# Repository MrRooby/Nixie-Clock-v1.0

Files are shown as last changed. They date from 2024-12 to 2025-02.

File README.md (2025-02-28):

# Nixie Clock v1.0

An ESP32-based Nixie Clock project featuring:
- Time and date display
- Temperature and humidity readings
- Gas level alarm detection
- Bluetooth control for alarm clock

## Table of Contents
1. [Introduction](#introduction)
2. [Features](#features)
3. [Hardware Setup](#hardware-setup)
4. [Bluetooth Application](#bluetooth-application)
5. [Schematic and Board Photos](#schematic-and-board-photos)
6. [Device Photos](#device-photos)
7. [**Issues**](#issues)

## Introduction
This project displays the current time, date, temperature, and humidity on Z573M Nixie tubes. It also includes a gas sensor alarm, and Bluetooth set alarm clock connectivity.

## Features
- Displays time in HH:MM format on Nixie tubes
- Shows date in DD-MM format
- Reads temperature and humidity via a DHT22 sensor
- Detects gas levels using an MQ-9 sensor
- Allows alarm configuration via Bluetooth
- Alerts with a buzzer and LEDs

## Hardware Setup
1. Nixie tubes are connected to 170V and are driven via K155ID.
2. Drivers responsible for the lamps are connected to ESP32 via Level Shifters (3.3V to 5V)
3. Two of the drivers are connected to PCF8575 I2C port expander.
4. RTC clock is connected to the board for time keeping
5. DHT and MQ-9 sensors are connected directly to the ESP32 pins.
6. Buzzer and LEDs are connected directly to the ESP32

## Bluetooth Application
*(pending)*

## Schematic and Board Photos
Schematic

Board

## Device Photos
nixie_clock v1

## Issues
The device's current version suffers from a couple of mistakes or errors.
1. Mirrored Z573M library. **Temporary fix:** Lamps connected from the bottom of the board.
2. Board enters boot-loop. **Temporary fix:** Button connected between IO12 and GND. If pressed, the board exits the boot loop and functions properly.
3. Wrong MQ9 input voltage. Sensor requires 5V and connected trace supplies 3.3V. **Temporary fix:** Cable connected to 5V omitting on-board trace.
4. LED pins don't supply enough current via PCF8575 **Temporary fix:** LEDs connected directly to ESP32

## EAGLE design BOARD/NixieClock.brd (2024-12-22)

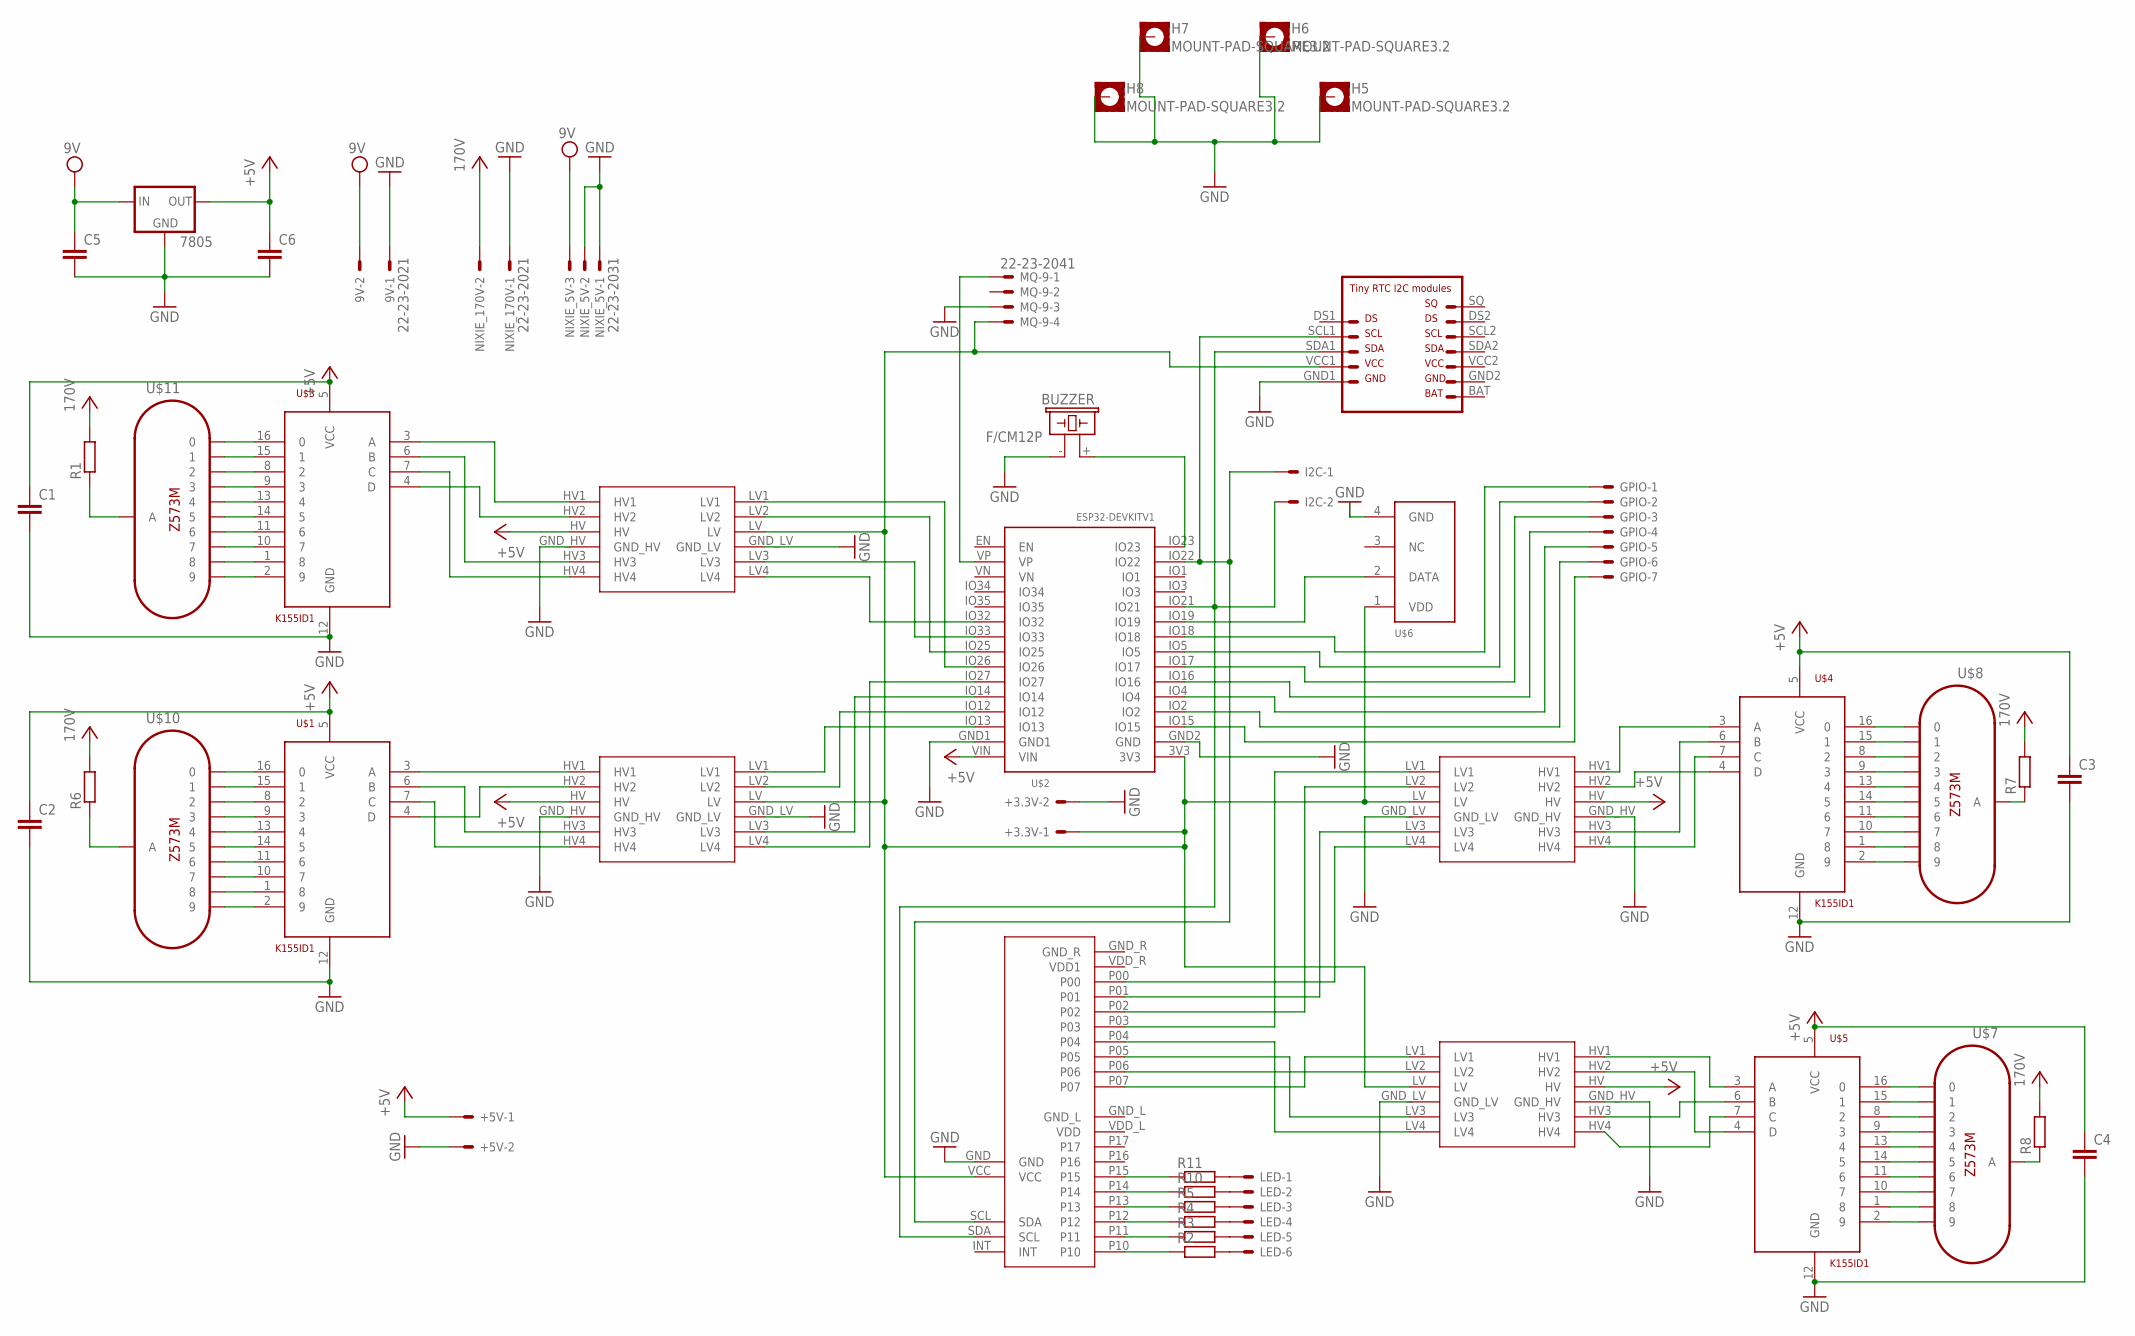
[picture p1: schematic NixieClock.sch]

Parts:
9V: 22-23-2021
7805: 78XXS
+3.3V, +5V: KK-156-2
BUZZER: F/CM12P
C1, C2, C3, C4, C5, C6: C2,5-3; C2.5-3
GPIO: KK-156-7
H5, H6, H7, H8: MOUNT-PAD-SQUARE3.2; 3,2-PAD-SQUARE
I2C: KK-156-2
LED: KK-156-6
MQ-9: 22-23-2041; MPN wyświetlacz I2C
NIXIE_5V: 22-23-2031
NIXIE_170V: 22-23-2021
R1, R2, R3, R4, R5, R6, R7, R8, R10, R11: R-EU_0204/7; 0204/7
STEP_UP_$: LEVEL-CONVERTER
U$1, U$3, U$4, U$5: K155ID1; DIP16-2.54-19.2X7.62MM
U$2: ESP32DEVKITV1; ESP32-DEVKITV1
U$6: DHT11
U$7, U$8, U$10, U$11: Z573M
U$9: RTC
U$12, U$13, U$15: LEVEL-CONVERTER
U$16: PCF8575

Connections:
3.3V: +3.3V.1, MQ-9.4, STEP_UP_$.LV, U$2.3V3, U$6.1 (VDD), U$9.VCC1, U$12.LV, U$13.LV, U$15.LV, U$16.VCC
170V: 9V.2, 7805.IN, C5.1, NIXIE_5V.3, NIXIE_170V.2, R1.2, R6.2, R7.2, R8.2
+5V: 7805.OUT, +5V.1, C1.1, C2.1, C3.1, C4.1, C6.1, STEP_UP_$.HV, U$1.5 (VCC), U$2.VIN, U$3.5 (VCC), U$4.5 (VCC), U$5.5 (VCC), U$12.HV, U$13.HV, U$15.HV
GND: 9V.1, 7805.GND, +3.3V.2, +5V.2, BUZZER.- (2), C1.2, C2.2, C3.2, C4.2, C5.2, C6.2, H5.B3,2, H6.B3,2, H7.B3,2, H8.B3,2, MQ-9.3, NIXIE_5V.1, NIXIE_5V.2, NIXIE_170V.1, STEP_UP_$.GND_HV, STEP_UP_$.GND_LV, U$1.12 (GND), U$2.GND1, U$2.GND2 (GND), U$3.12 (GND), U$4.12 (GND), U$5.12 (GND), U$6.4 (GND), U$9.GND1, U$12.GND_HV, U$12.GND_LV, U$13.GND_HV, U$13.GND_LV, U$15.GND_HV, U$15.GND_LV, U$16.GND
unnamed: STEP_UP_$.HV1, U$5.3 (A)
unnamed: STEP_UP_$.HV2, U$5.4 (D)
unnamed: STEP_UP_$.HV3, U$5.6 (B)
unnamed: STEP_UP_$.HV4, U$5.7 (C)
unnamed: U$15.LV4, U$16.P00
unnamed: U$4.3 (A), U$15.HV1
unnamed: U$4.4 (D), U$15.HV2
unnamed: U$4.6 (B), U$15.HV3
unnamed: U$3.3 (A), U$13.HV1
unnamed: U$3.4 (D), U$13.HV2
unnamed: U$3.6 (B), U$13.HV3
unnamed: U$3.7 (C), U$13.HV4
unnamed: U$1.3 (A), U$12.HV1
unnamed: U$1.4 (D), U$12.HV2
unnamed: U$1.6 (B), U$12.HV3
unnamed: U$1.7 (C), U$12.HV4
unnamed: U$3.16 (0), U$11.K0 (0)
unnamed: U$3.15 (1), U$11.K1 (1)
unnamed: U$3.8 (2), U$11.K2 (2)
unnamed: U$3.9 (3), U$11.K3 (3)
unnamed: U$3.13 (4), U$11.K4 (4)
unnamed: U$3.14 (5), U$11.K5 (5)
unnamed: U$3.11 (6), U$11.K6 (6)
unnamed: U$3.10 (7), U$11.K7 (7)
unnamed: U$3.1 (8), U$11.K8 (8)
unnamed: U$3.2 (9), U$11.K9 (9)
unnamed: U$1.16 (0), U$10.K0 (0)
unnamed: U$1.15 (1), U$10.K1 (1)
unnamed: U$1.8 (2), U$10.K2 (2)
unnamed: U$1.9 (3), U$10.K3 (3)
unnamed: U$1.13 (4), U$10.K4 (4)
unnamed: U$1.14 (5), U$10.K5 (5)
unnamed: U$1.11 (6), U$10.K6 (6)
unnamed: U$1.10 (7), U$10.K7 (7)
unnamed: U$1.1 (8), U$10.K8 (8)
unnamed: U$1.2 (9), U$10.K9 (9)
unnamed: U$5.16 (0), U$7.K0 (0)
unnamed: U$5.15 (1), U$7.K1 (1)
unnamed: U$5.8 (2), U$7.K2 (2)
unnamed: U$5.9 (3), U$7.K3 (3)
unnamed: U$5.13 (4), U$7.K4 (4)
unnamed: U$5.14 (5), U$7.K5 (5)
unnamed: U$5.11 (6), U$7.K6 (6)
unnamed: U$5.10 (7), U$7.K7 (7)
unnamed: U$5.1 (8), U$7.K8 (8)
unnamed: U$5.2 (9), U$7.K9 (9)
unnamed: U$4.2 (9), U$8.K9 (9)
unnamed: U$4.1 (8), U$8.K8 (8)
unnamed: U$4.10 (7), U$8.K7 (7)
unnamed: U$4.11 (6), U$8.K6 (6)
unnamed: U$4.14 (5), U$8.K5 (5)
unnamed: U$4.13 (4), U$8.K4 (4)
unnamed: U$4.9 (3), U$8.K3 (3)
unnamed: U$4.8 (2), U$8.K2 (2)
unnamed: U$4.15 (1), U$8.K1 (1)
unnamed: U$4.16 (0), U$8.K0 (0)
unnamed: U$15.LV3, U$16.P01
unnamed: U$2.IO27, U$12.LV4
unnamed: I2C.1, U$2.IO22, U$9.SCL1, U$16.SCL (SDA)
unnamed: I2C.2, U$2.IO21, U$9.SDA1, U$16.SDA (SCL)
unnamed: BUZZER.+ (1), U$2.IO23
unnamed: U$15.LV2, U$16.P02
unnamed: MQ-9.1, U$2.VP
unnamed: U$15.LV1, U$16.P03
unnamed: STEP_UP_$.LV4, U$16.P04
unnamed: STEP_UP_$.LV3, U$16.P05
unnamed: STEP_UP_$.LV2, U$16.P06
unnamed: STEP_UP_$.LV1, U$16.P07
unnamed: U$2.IO19, U$6.2 (DATA)
unnamed: GPIO.1, U$2.IO18
unnamed: GPIO.2, U$2.IO5
unnamed: U$2.IO26, U$13.LV1
unnamed: U$2.IO25, U$13.LV2
unnamed: U$2.IO33, U$13.LV3
unnamed: U$2.IO32, U$13.LV4
unnamed: U$2.IO13, U$12.LV1
unnamed: U$2.IO12, U$12.LV2
unnamed: U$2.IO14, U$12.LV3
unnamed: R8.1, U$7.A
unnamed: R7.1, U$8.A
unnamed: R6.1, U$10.A
unnamed: R1.1, U$11.A
unnamed: GPIO.3, U$2.IO17
unnamed: R2.1, U$16.P10
unnamed: R3.1, U$16.P11
unnamed: R4.1, U$16.P12
unnamed: R5.1, U$16.P13
unnamed: R10.1, U$16.P14
unnamed: R11.1, U$16.P15
unnamed: LED.1, R11.2
unnamed: LED.2, R10.2
unnamed: LED.3, R5.2
unnamed: LED.4, R4.2
unnamed: LED.5, R3.2
unnamed: LED.6, R2.2
unnamed: GPIO.4, U$2.IO16
unnamed: GPIO.5, U$2.IO4
unnamed: GPIO.6, U$2.IO2
unnamed: GPIO.7, U$2.IO15
unnamed: U$4.7 (C), U$15.HV4

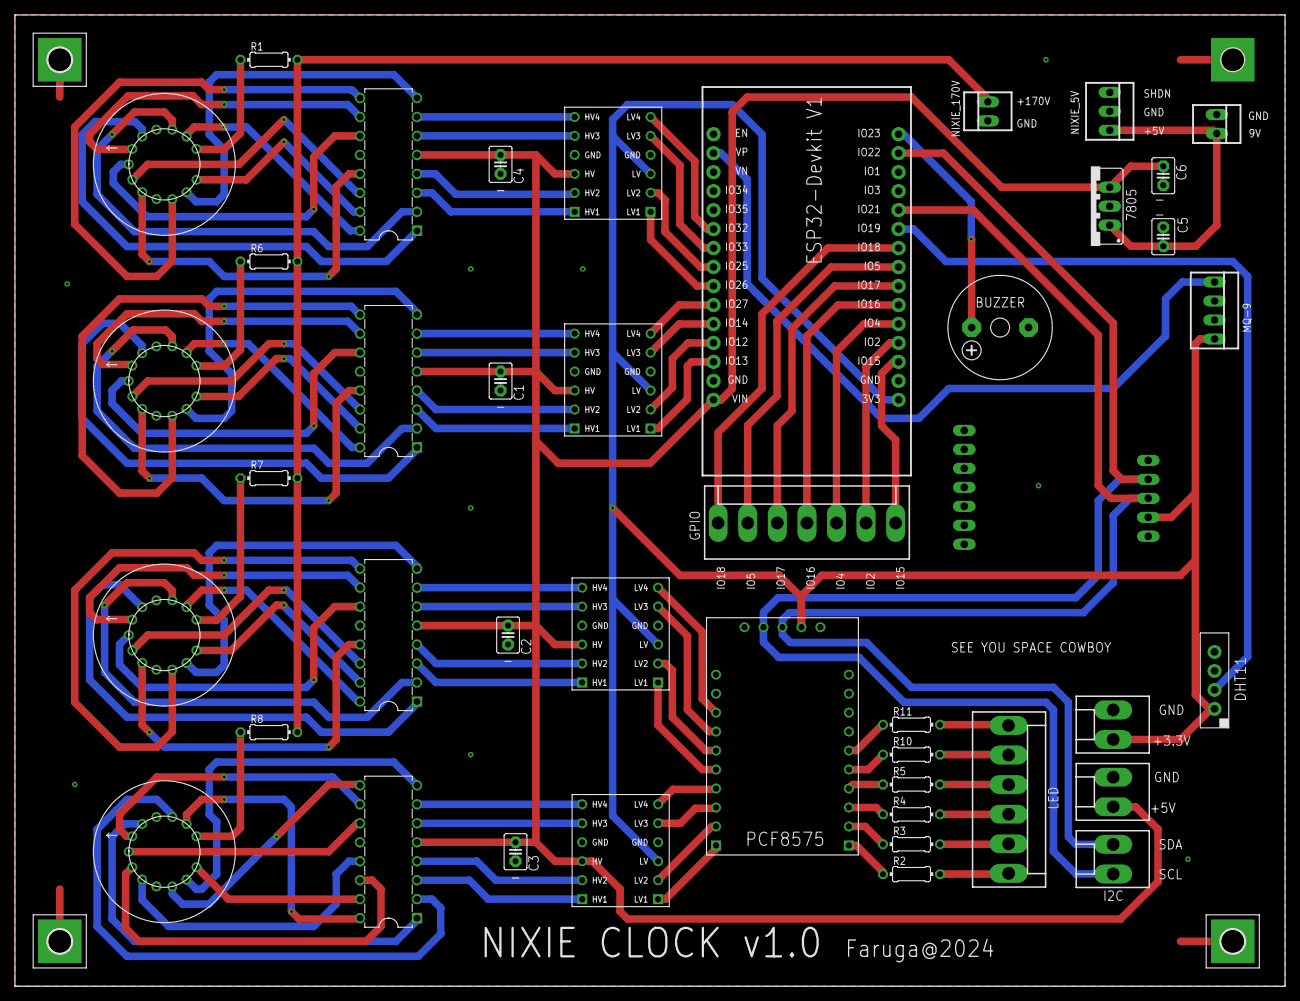
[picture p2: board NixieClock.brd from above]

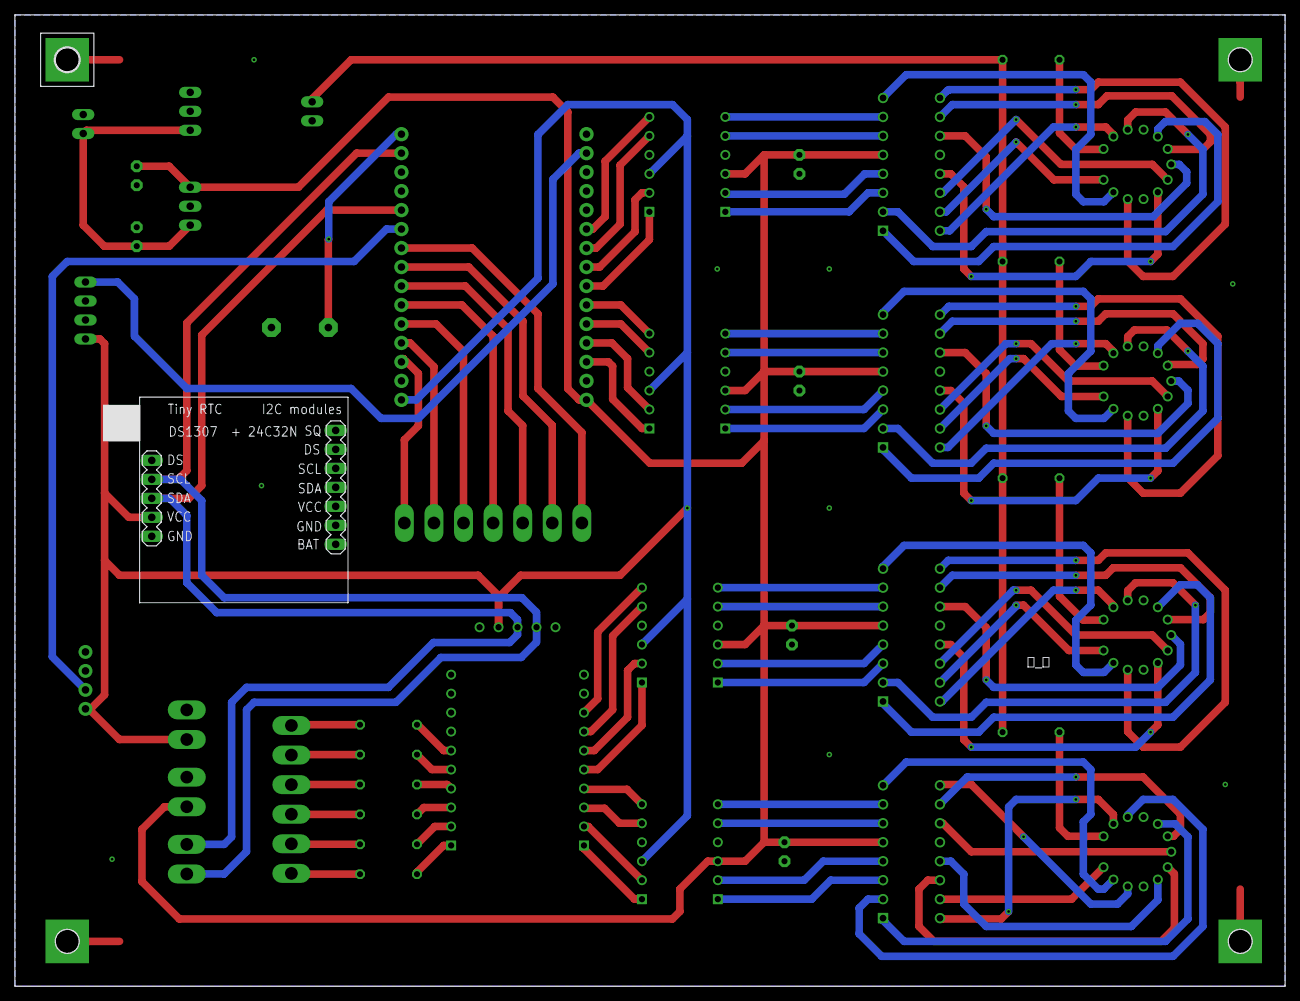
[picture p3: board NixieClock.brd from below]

Board: 2 copper layers, 170.0 x 130.0 mm, 47 parts (2 on the bottom side), 104 nets.

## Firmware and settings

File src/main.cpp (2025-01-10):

#include <Arduino.h>
#include <Wire.h>
#include <config.h>

#include "lamps.h"
#include "sensors.h"
#include "inputOutput.h"
#include "program.h"
#include "timeMenager.h"
#include "BTCon.h"


Sensors sensors;
Lamps lamps;
InputOutput inputOutput;
Program program;
TimeMenager timeMenager;
BTCon btCon;

unsigned int option = 0;


void setup() 
{
  Serial.begin(9600);

  lamps.setupLamps();

  sensors.setupSensors();

  inputOutput.setupIO();

  btCon.setupBT();
}

void loop() 
{
  if(inputOutput.isSwitchModeButtonPressed())
  {
    option++;
    if(option > 3)
    {
      option = 0;
    }
  }

  sensors.runSensors(2000);
  
  program.runGasLevelAlarm();

  btCon.runBT(timeMenager);

  timeMenager.runAlarmClock();
  
  program.displayOption(option, sensors);
}

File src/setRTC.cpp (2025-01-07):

/* A copy-paste code for setting up the DS1307 RTC*/

/*Before running set the secondsOffset variable to take
the compilation and upload time into consideration to make sure
the time is reliable */

// #include <Arduino.h>
// #include <Wire.h>
// #include <Time.h>
// #include <DS1307RTC.h>

// const char *monthName[12] = {
//   "Jan", "Feb", "Mar", "Apr", "May", "Jun",
//   "Jul", "Aug", "Sep", "Oct", "Nov", "Dec"
// };

// tmElements_t tm;

// bool getTime(const char *str)
// {
//   int Hour, Min, Sec;

//   if (sscanf(str, "%d:%d:%d", &Hour, &Min, &Sec) != 3) return false;
//   tm.Hour = Hour;
//   tm.Minute = Min;
//   tm.Second = Sec;
//   return true;
// }

// bool getDate(const char *str)
// {
//   char Month[12];
//   int Day, Year;
//   uint8_t monthIndex;

//   if (sscanf(str, "%s %d %d", Month, &Day, &Year) != 3) return false;
//   for (monthIndex = 0; monthIndex < 12; monthIndex++) {
//     if (strcmp(Month, monthName[monthIndex]) == 0) break;
//   }
//   if (monthIndex >= 12) return false;
//   tm.Day = Day;
//   tm.Month = monthIndex + 1;
//   tm.Year = CalendarYrToTm(Year);
//   return true;
// }

// void setup() {
//   bool parse=false;
//   bool config=false;

//   // get the date and time the compiler was run
//   if (getDate(__DATE__) && getTime(__TIME__)) {
//     parse = true;
//     // and configure the RTC with this info
//     if (RTC.write(tm)) {
//       config = true;
//     }
//   }

//   Serial.begin(9600);
//   while (!Serial) ; // wait for Arduino Serial Monitor
//   delay(200);
//   if (parse && config) {
//     Serial.print("DS1307 configured Time=");
//     Serial.print(__TIME__);
//     Serial.print(", Date=");
//     Serial.println(__DATE__);
//   } else if (parse) {
//     Serial.println("DS1307 Communication Error :-{");
//     Serial.println("Please check your circuitry");
//   } else {
//     Serial.print("Could not parse info from the compiler, Time=\"");
//     Serial.print(__TIME__);
//     Serial.print("\", Date=\"");
//     Serial.print(__DATE__);
//     Serial.println("\"");
//   }
// }

// void loop() {

// }

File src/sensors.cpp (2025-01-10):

#include "sensors.h"

void Sensors::setupSensors(){
    dht.begin();
}

void Sensors::runSensors(int refreshRateMillis)
{
    unsigned long currentMillis = millis();
    if (currentMillis - lastSensorRunMillis >= refreshRateMillis) {
        dhtTemperature = dht.readTemperature();
        dhtHumidity = dht.readHumidity();
        if(isnan(dhtTemperature) || isnan(dhtHumidity))
        {
            dhtTemperature = 99;
            dhtHumidity = 99;
        }
        lastSensorRunMillis = currentMillis;
        printDHTToSerial();
    }


}

std::pair<unsigned int, unsigned int> Sensors::getTemperature()
{
    unsigned int roundedTemp = static_cast<int>(dhtTemperature + 0.5);
    unsigned int tempTens = roundedTemp / 10;
    if (tempTens > 9) { tempTens = 9; }
    unsigned int tempOnes = roundedTemp % 10;

    return std::make_pair(tempTens, tempOnes);
} 

std::pair<unsigned int, unsigned int> Sensors::getHumidity()
{
    unsigned int roundedHum = static_cast<int>(dhtHumidity + 0.5);
    unsigned int humTens = roundedHum / 10;
    if (humTens > 9) { humTens = 9; }
    unsigned int humOnes = roundedHum % 10; 

    return std::make_pair(humTens, humOnes);
}

void Sensors::calibrateMQ9Sensor()
{
    float sensor_volt;  
    float RS_air; //  Rs in clean air 
    float R0;  // R0 in 1000 ppm LPG 
    float sensorValue; 
    
    //Average   
    for(int x = 0 ; x < 100 ; x++) 
    { 
        sensorValue = sensorValue + analogRead(MQ_PIN); 
    } 
    sensorValue = sensorValue/100.0; 
    
    sensor_volt = (sensorValue/1024) * 5.0; 
    RS_air = (5.0 - sensor_volt)/sensor_volt; // Depend on RL on yor module 
    R0 = RS_air/9.9; // According to MQ9 datasheet table 
    
    MQ9_R0 = R0;
}

float Sensors::getMQ9SensorData()
{
    int alarm = 0; 
    float sensor_volt; 
    float RS_gas; 
    float ratio; 
    //-Replace the name "R0" with the value of R0 in the demo of First Test -/ 
    float R0 = 0.91; 
    
    int sensorValue = analogRead(MQ_PIN); 
    sensor_volt = ((float)sensorValue / 4096) * 5.0; 
    RS_gas = (5.0 - sensor_volt) / sensor_volt; // Depend on RL on yor module 
    
    
    ratio = RS_gas / R0; // ratio = RS/R0 

    // Serial.print("Sensor value: ");
    // Serial.println(sensorValue);
    // Serial.print("sensor_volt = "); 
    // Serial.println(sensor_volt); 
    // Serial.print("RS_ratio = "); 
    // Serial.println(RS_gas); 
    // Serial.print("Rs/R0 = "); 
    // Serial.println(ratio); 
    
    // Serial.print("\n\n"); 

    return ratio;
}

bool Sensors::isGasLevelDangerous()
{
    if(getMQ9SensorData() < dangerGasLevel)
    {
        return true;
    }
    return false;
}

void Sensors::printDHTToSerial()
{
    Serial.print("Temperature: ");
    Serial.print(dhtTemperature);
    Serial.println(" *C");
    Serial.print("Humidity: ");
    Serial.print(dhtHumidity);
    Serial.println(" %");
}

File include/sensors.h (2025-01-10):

#pragma once
#include "DHT.h"
#include <utility>
#include <Adafruit_Sensor.h>

#define DHT22_PIN 19
#define DHTTYPE DHT22

#define MQ_PIN 36 // VP - Analog only

class Sensors {
    private:
        unsigned long lastSensorRunMillis = 0;
        unsigned int cachedTempTens = 0;
        unsigned int cachedTempOnes = 0;
    
        unsigned long lastHumidityReadMillis = 0;
        unsigned int cachedHumTens = 0;
        unsigned int cachedHumOnes = 0;

        float MQ9_R0 = 0.91; // Value to be changed after calibration
        float dangerGasLevel = 1.1;

        float dhtTemperature = 0;
        float dhtHumidity = 0;

        float mq9SensorData = 0;
    public:

        DHT dht = DHT(DHT22_PIN, DHTTYPE);


        /*!
            * @brief  Setup pins, objects and run sensor for the DHT11 and MQ9 sensors
        */
        void setupSensors();

        /*!
            *  @brief Refresh the sensor data
            *  @param refreshRateMillis Refresh rate in milliseconds
        */
        void runSensors(int refreshRateMillis);  

        /*!
            *  @brief  Get the temperature from the DHT11 sensor to display on the Nixie tubes
            *  @return Pair of unsigned int values representing the tens and ones of the temperature
        */
        std::pair<unsigned int, unsigned int> getTemperature();  

        /*!
            *  @brief  Get the humidity from the DHT11 sensor to display on the Nixie tubes
            *  @return Pair of unsigned int values representing the tens and ones of the humidity
        */
        std::pair<unsigned int, unsigned int> getHumidity();

        /*!
            *  @brief  Get average R0 value for proper calibration of the MQ9 sensor
                       For this function to return the correct value, the MQ9 sensor must be exposed to clean air
                       and run after 48h heating up period
        */
        void calibrateMQ9Sensor();
        
        /*!
            *  @brief  Get the RS/R0 ratio value of the gas from the MQ9 sensor
            *  @param choice 'c' for CO, 'l' for LPG, 'm' for Methane
            *  @return Integer value representing the sensor data
        */
        float getMQ9SensorData();

        /*!
            *  @brief  Check if the gas level is dangerous
            *  @return True if the gas level is dangerous
        */
        bool isGasLevelDangerous();

        /*!
            *  @brief  Print the DHT11 sensor data to the serial monitor
        */
        void printDHTToSerial();

};

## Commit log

2024-12-22 Added .sch and .brd files
    [NixieClock.brd, NixieClock.sch]
2024-12-22 ixed K155ID1 pin definitions. Added functions to display temperature and humidity on the nixie lamps
2024-12-22 implemented OOP for lamps and sensors to improve code clarity
2024-12-22 added class for handling and parsing time data from the RTC to display on the lamps. Changed all uint_least8_t variables to unsigned int due to error with division
    [lamps.cpp, main.cpp, sensors.cpp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]
2024-12-25 TODO: Implement CO2 read function, implement APP, implement alarm clock with a snooze button
2025-01-06 added MQ9 support. Fixed all other issues accept DHT11 mismatched data
    [inputOutput.cpp, lamps.cpp, main.cpp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]
2025-01-08 added blinking leds when gas alarm is activated, fixed temperature and humidity displaying
    [inputOutput.cpp, main.cpp, program.cpp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]
2025-01-10 updated DHT sensor type to DHT22, adjusted sensor refresh rate, and commented out temperature and humidity display
